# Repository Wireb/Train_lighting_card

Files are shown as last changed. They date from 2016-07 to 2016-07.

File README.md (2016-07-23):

### Induction refractory furnance supporting files

### licence 
Copyright (c) 2015 Peter Shabino

Permission is hereby granted, free of charge, to any person obtaining a copy of this hardware, software, and associated documentation files
(the "Product"), to deal in the Product without restriction, including without limitation the rights to use, copy, modify, merge, publish,
distribute, sublicense, and/or sell copies of the Product, and to permit persons to whom the Product is furnished to do so, subject to the
following conditions:

The above copyright notice and this permission notice shall be included in all copies or substantial portions of the Product.

THE PRODUCT IS PROVIDED "AS IS", WITHOUT WARRANTY OF ANY KIND, EXPRESS OR IMPLIED, INCLUDING BUT NOT LIMITED TO THE WARRANTIES OF
MERCHANTABILITY, FITNESS FOR A PARTICULAR PURPOSE AND NONINFRINGEMENT. IN NO EVENT SHALL THE AUTHORS OR COPYRIGHT HOLDERS BE LIABLE
FOR ANY CLAIM, DAMAGES OR OTHER LIABILITY, WHETHER IN AN ACTION OF CONTRACT, TORT OR OTHERWISE, ARISING FROM, OUT OF OR IN CONNECTION
WITH THE PRODUCT OR THE USE OR OTHER DEALINGS IN THE PRODUCT.

### What is it
The current generation of controller card supports up to 11 normal LED channels plus one "special"  one that supports driving a bi-polar output. On the input side the controller will run off 6V to 60V AC or DC. (note I have NOT test this full range. I have tested 9Vac to 20Vac with no issues) It also has 4 opto-isolated inputs that will respond to ~3V to 32V AC or DC that can be used to pick one of 16 pre-programmed states. 

Currently there are 7 selectable states:
* Headlights
* running lights
* left turn
* right turn
* break lights
* reverse lights
* light bar flashers 

Via the programing button any state, combination of states, or none can be chosen for each of the 16 combinations of the 4 inputs.

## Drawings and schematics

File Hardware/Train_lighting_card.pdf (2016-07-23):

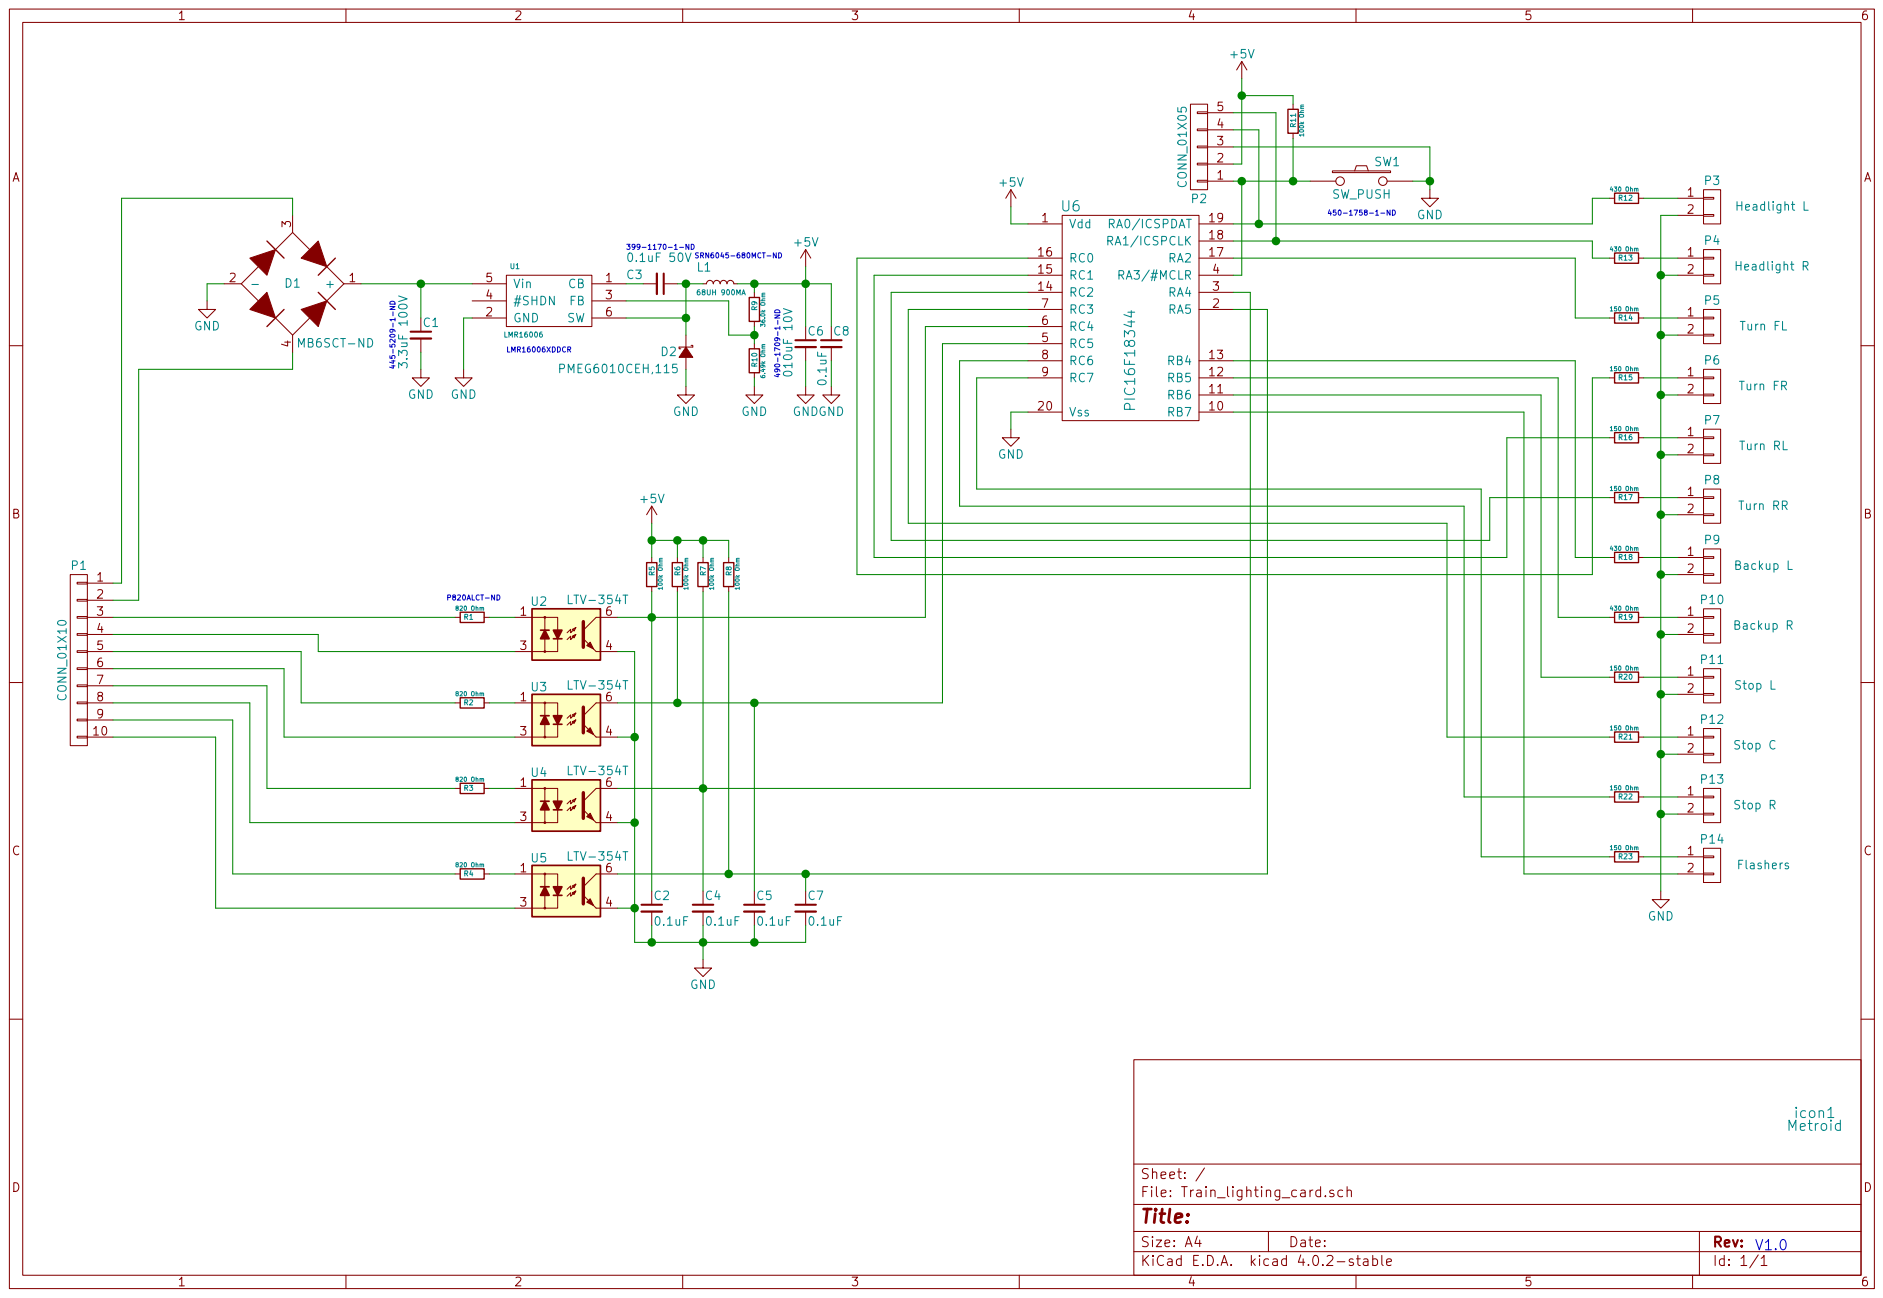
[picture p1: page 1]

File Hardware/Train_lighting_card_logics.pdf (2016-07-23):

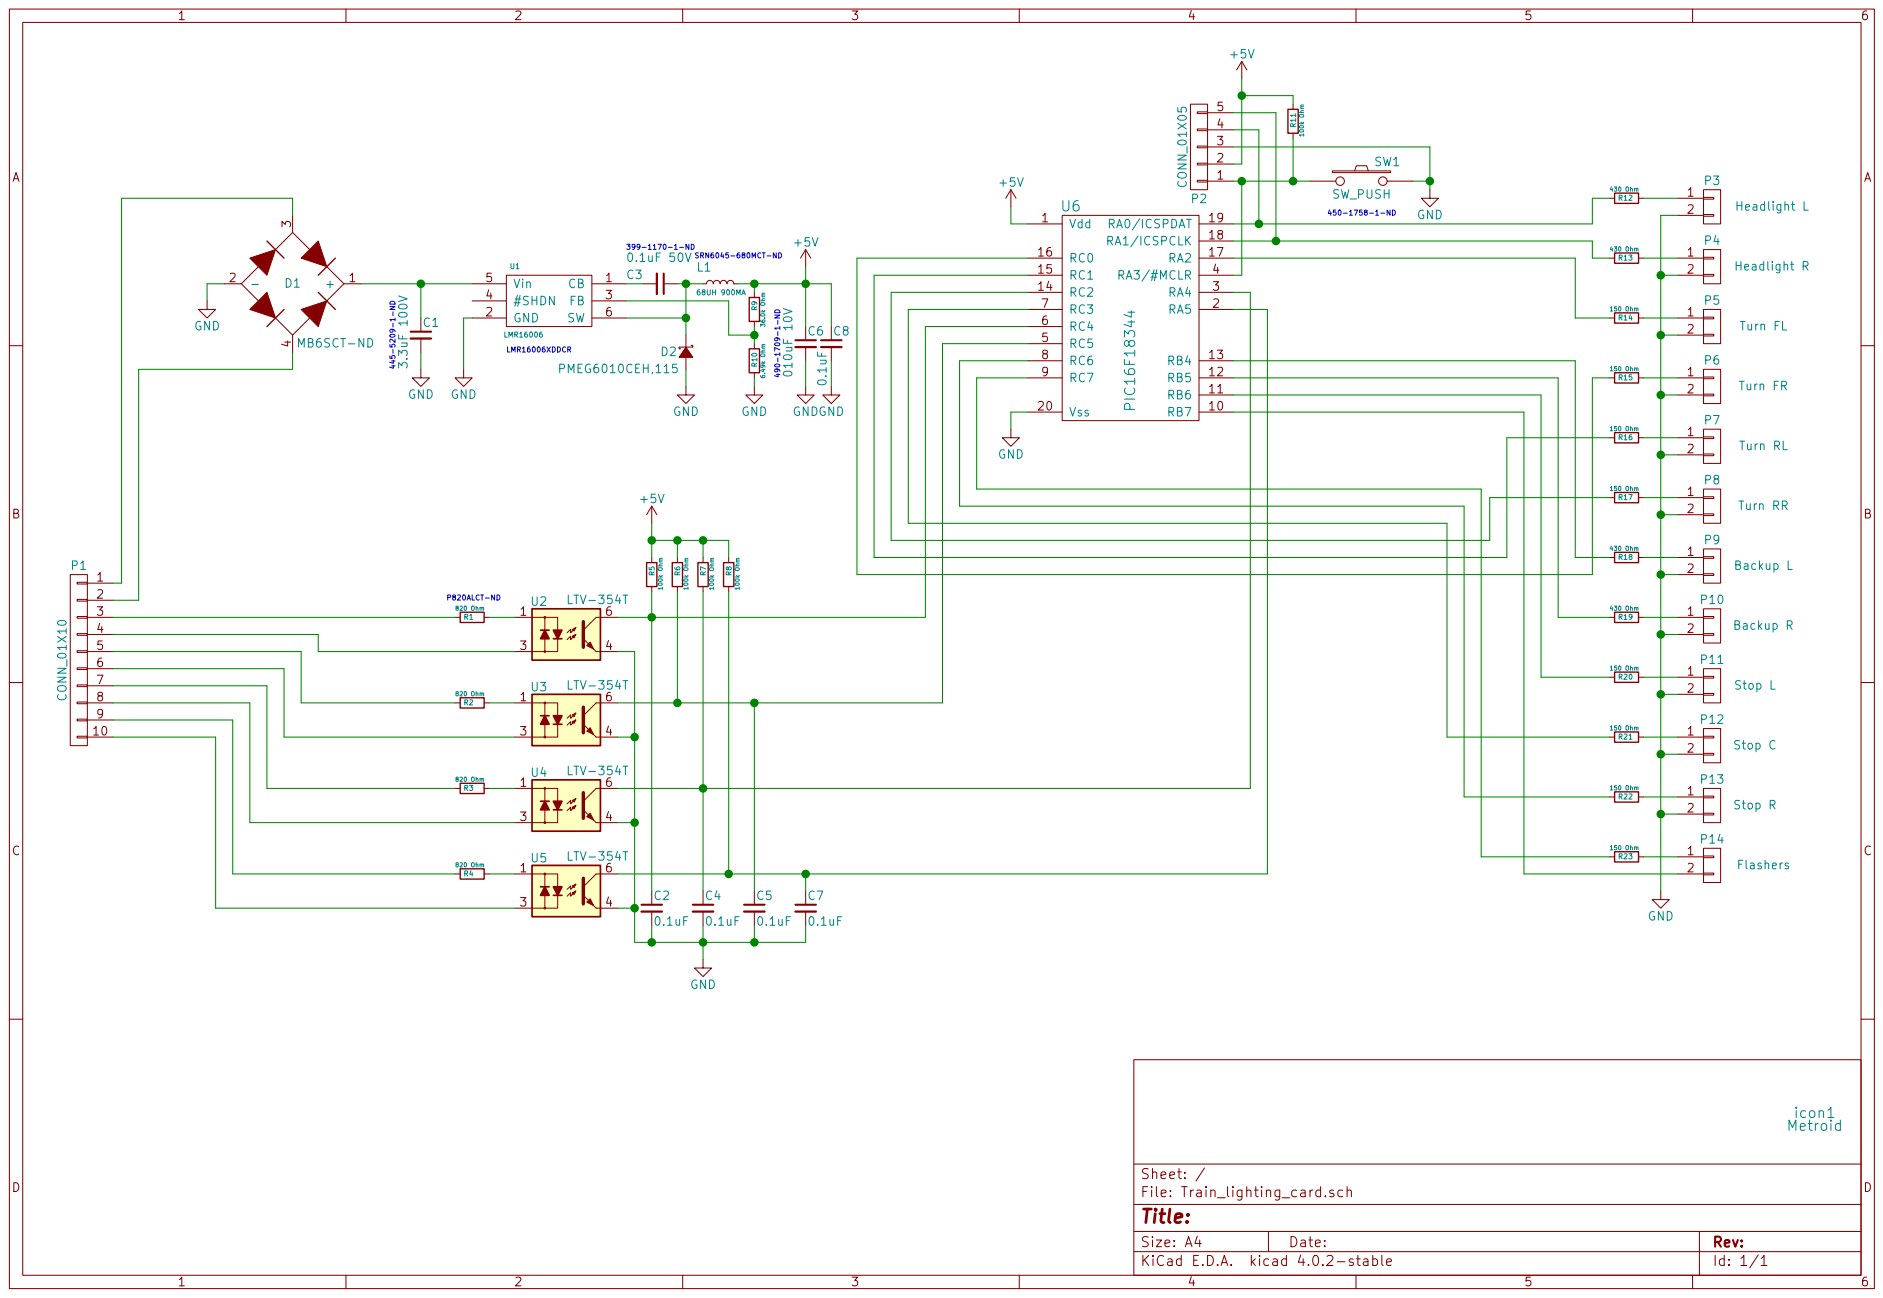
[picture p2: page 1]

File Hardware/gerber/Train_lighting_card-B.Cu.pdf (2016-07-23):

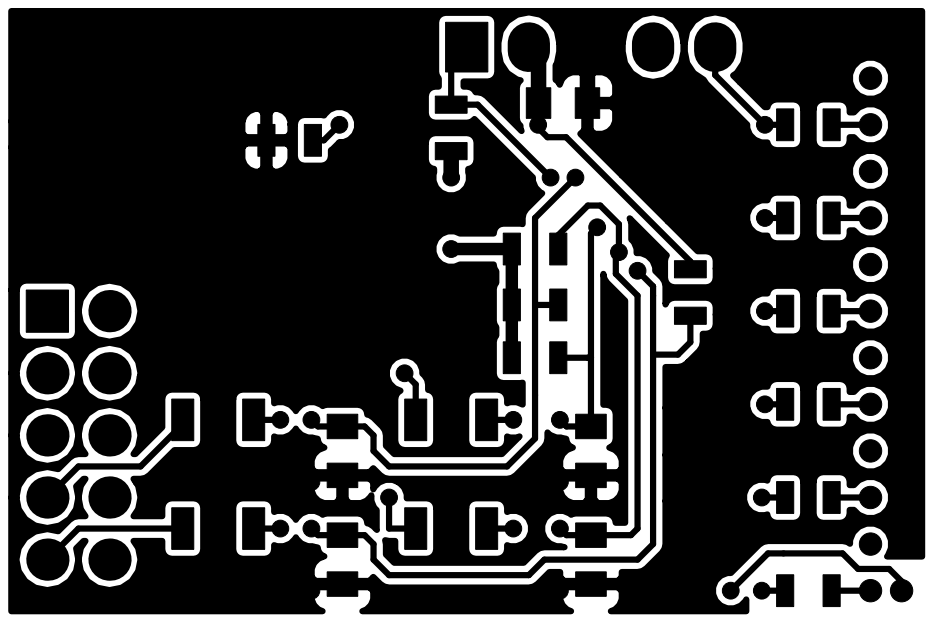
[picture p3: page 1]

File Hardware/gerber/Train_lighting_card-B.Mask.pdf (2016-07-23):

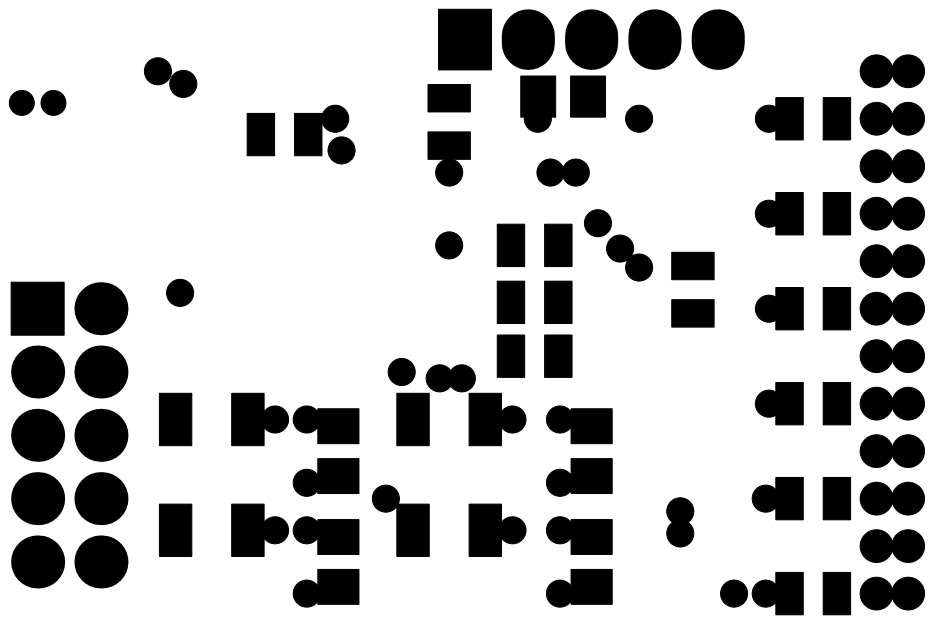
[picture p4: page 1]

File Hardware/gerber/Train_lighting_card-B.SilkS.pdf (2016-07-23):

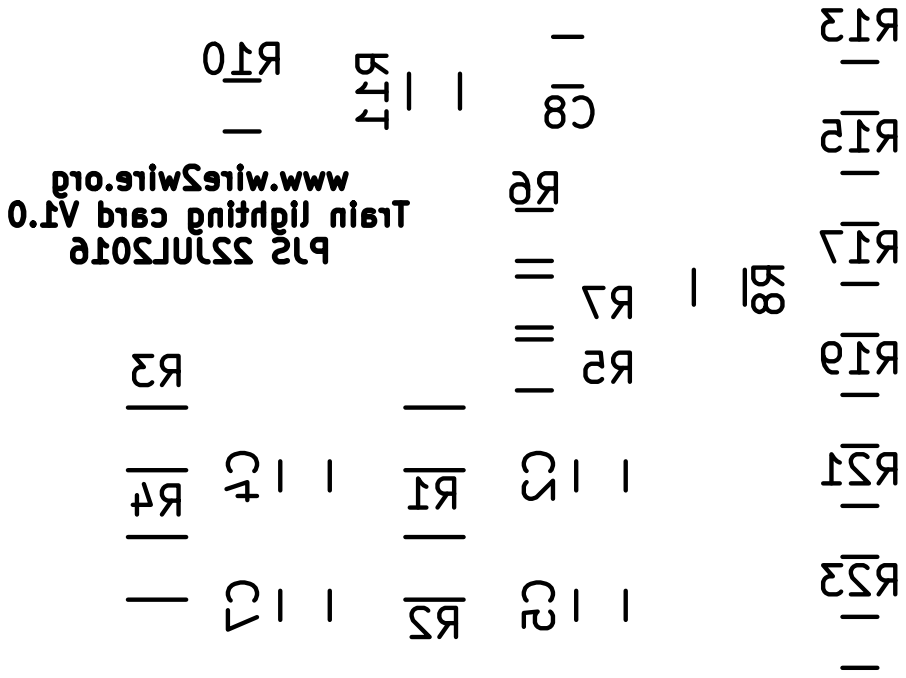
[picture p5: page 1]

Train lighting card V1.0 PJS 22JUL2016 C4 C2 C7 C5 R1 R2 R3 R4 R5 R6 R7 R8 R10 R11 R13 R15 R17 R19 R21 R23 C8

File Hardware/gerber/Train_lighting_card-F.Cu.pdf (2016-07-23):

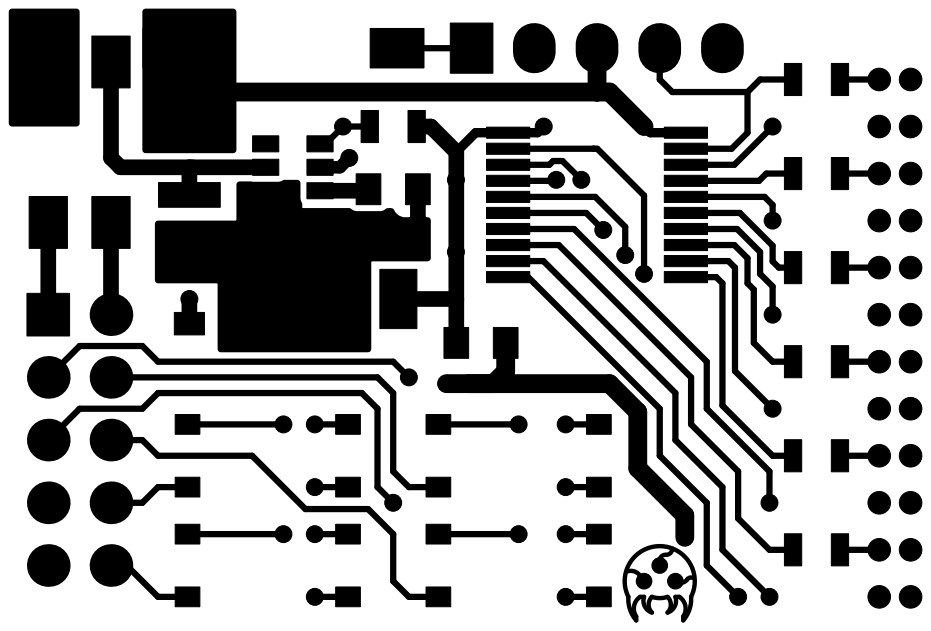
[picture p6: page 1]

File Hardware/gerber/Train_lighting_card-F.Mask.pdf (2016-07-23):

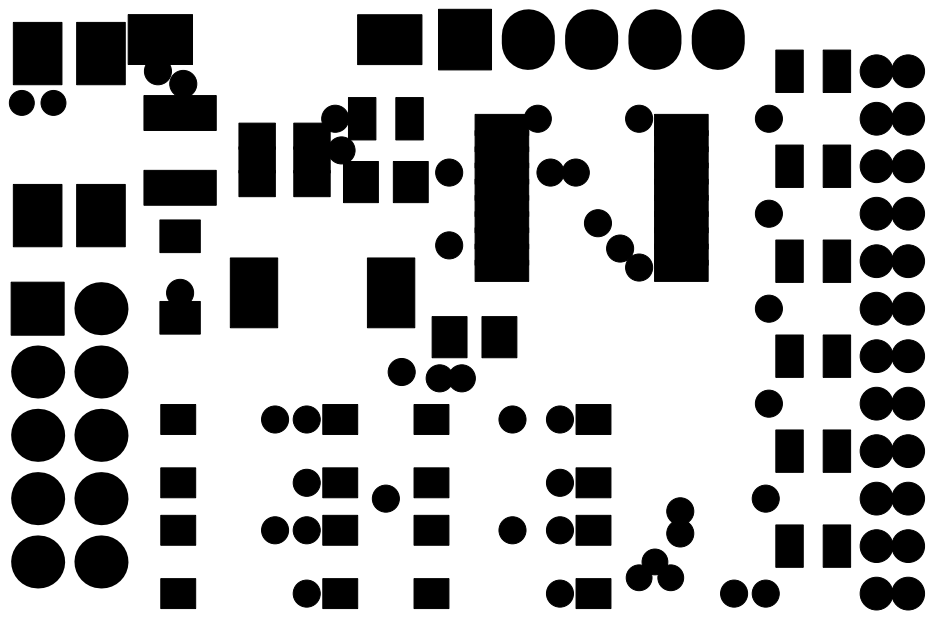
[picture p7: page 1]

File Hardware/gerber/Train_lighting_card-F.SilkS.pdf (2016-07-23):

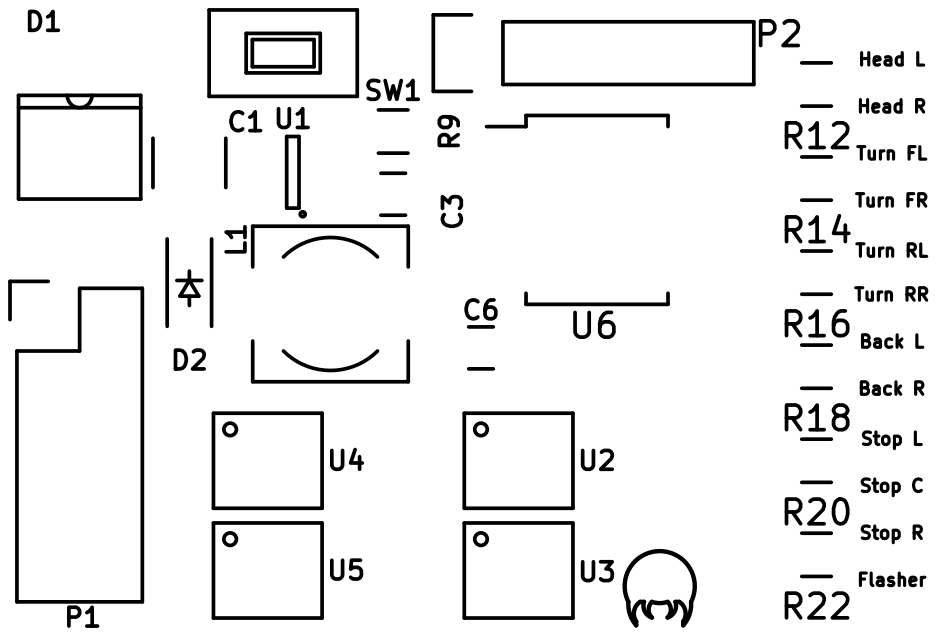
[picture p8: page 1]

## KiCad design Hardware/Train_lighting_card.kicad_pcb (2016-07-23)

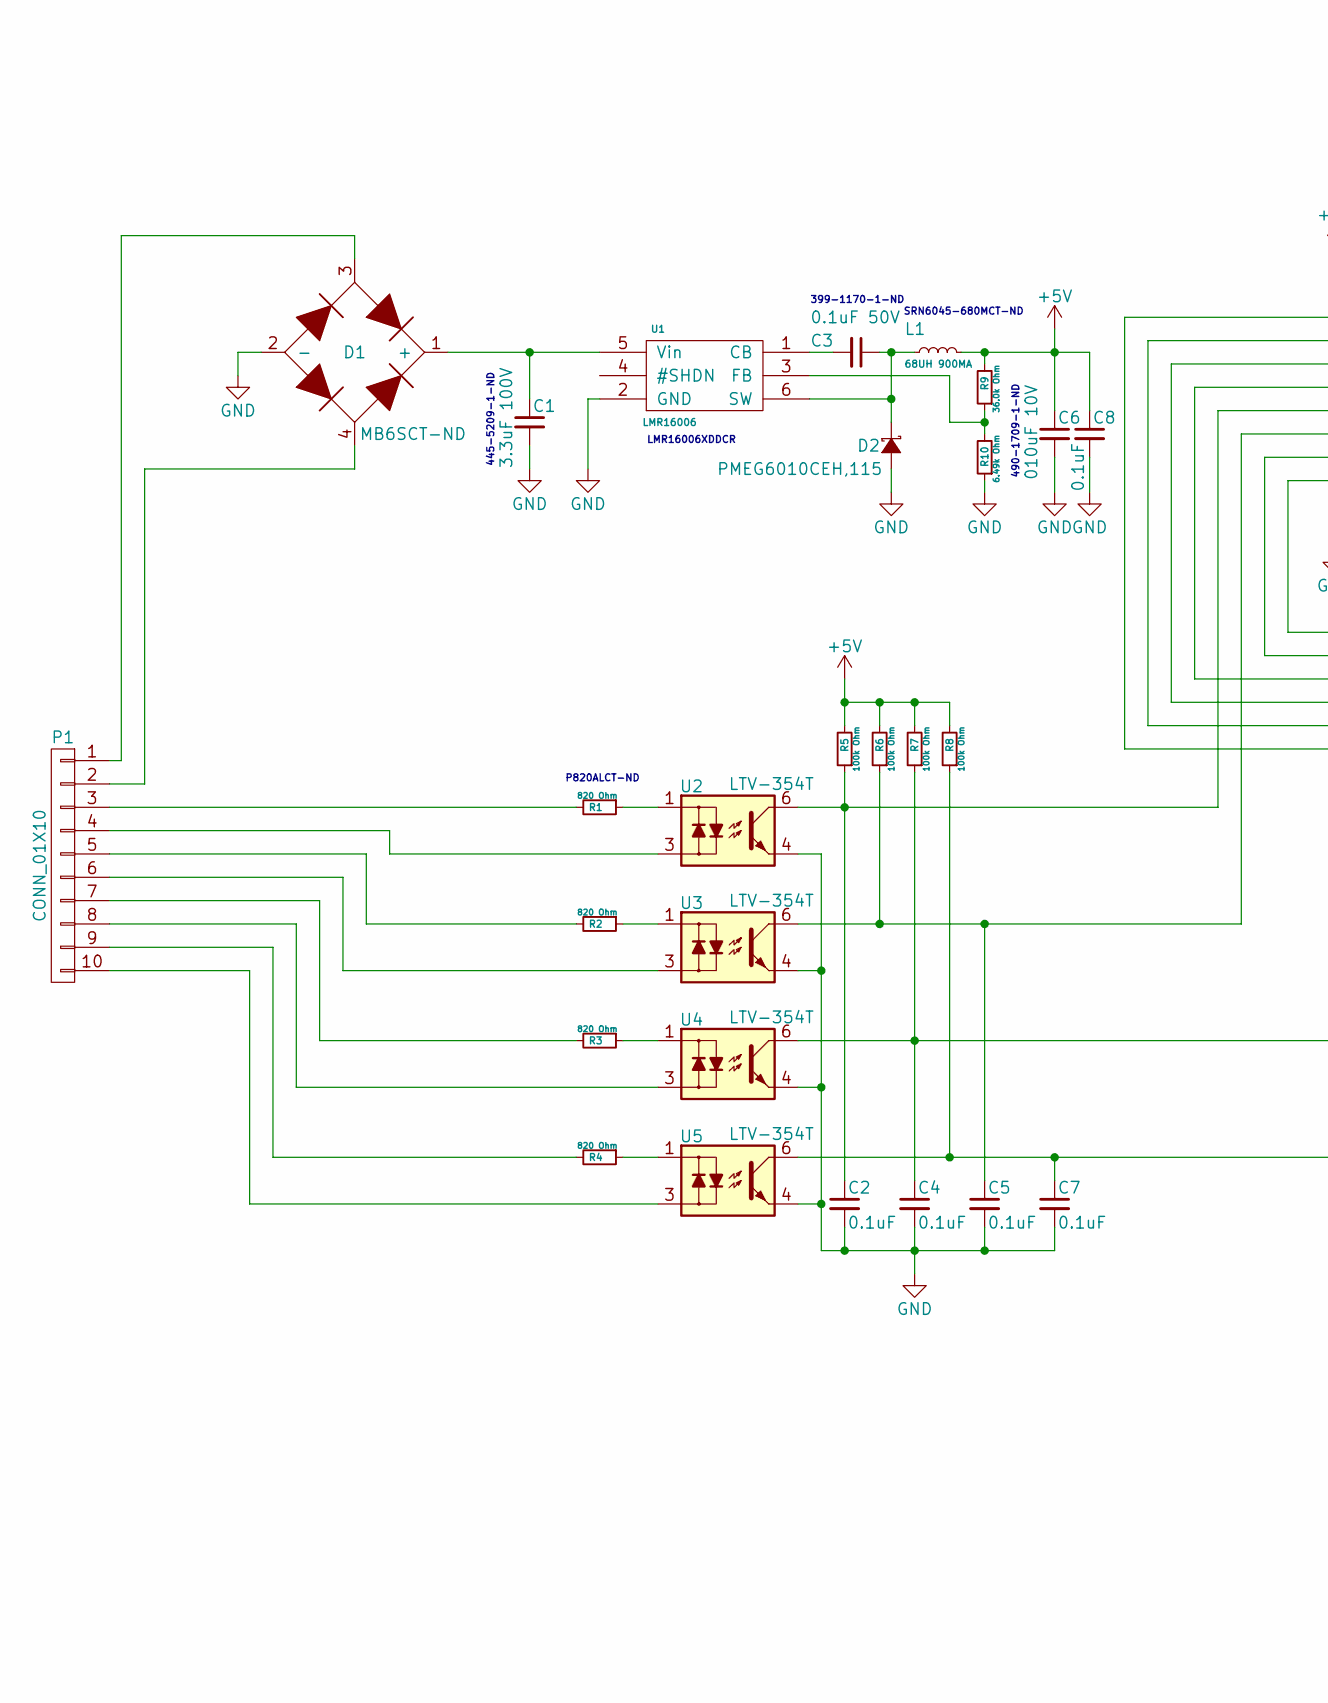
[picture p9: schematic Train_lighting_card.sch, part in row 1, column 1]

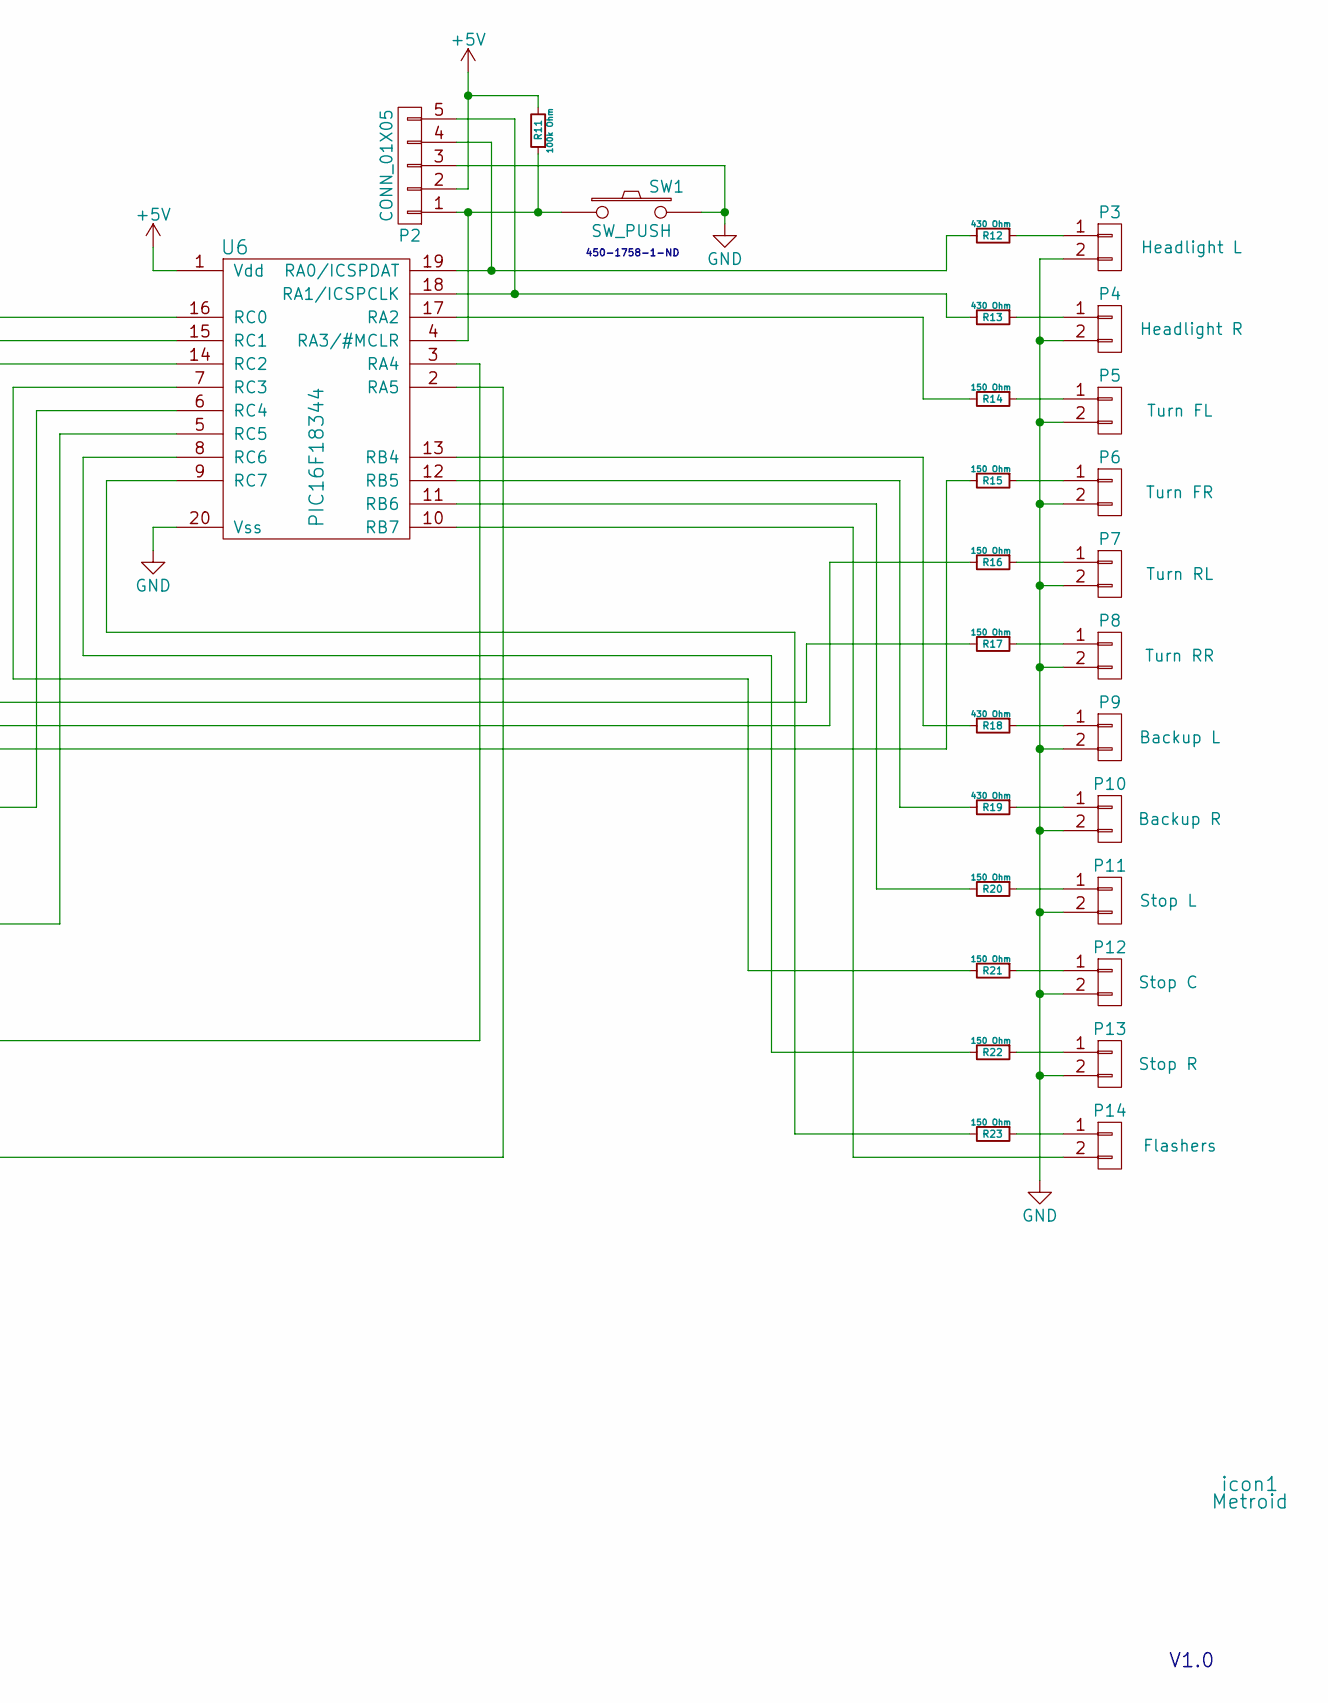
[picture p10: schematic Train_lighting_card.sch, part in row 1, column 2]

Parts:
C1: 3.3uF 100V; C_1210
C2, C4, C5, C7, C8: 0.1uF; C_0805
C3: 0.1uF 50V; C_0805
C6: 010uF 10V; C_0805
D1: MB6SCT-ND
D2: PMEG6010CEH,115; SOD-123
L1: 68UH 900MA; Choke_SMD_6.3x6.3_H3
P1: CONN_01X10; Pin_Header_Straight_2x05
P2: CONN_01X05; Pin_Header_Straight_1x05
P3: Headlight L; wirepad_x2_20mil
P4: Headlight R; wirepad_x2_20mil
P5: Turn FL; wirepad_x2_20mil
P6: Turn FR; wirepad_x2_20mil
P7: Turn RL; wirepad_x2_20mil
P8: Turn RR; wirepad_x2_20mil
P9: Backup L; wirepad_x2_20mil
P10: Backup R; wirepad_x2_20mil
P11: Stop L; wirepad_x2_20mil
P12: Stop C; wirepad_x2_20mil
P13: Stop R; wirepad_x2_20mil
P14: Flashers; wirepad_x2_20mil
R1, R2, R3, R4: 820 Ohm; R_1206
R5, R6, R7, R8, R11: 100k Ohm; R_0805
R9: 36.0k Ohm; R_0805
R10: 6.49k Ohm; R_0805
R12, R13, R18, R19: 430 Ohm; R_0805
R14, R15, R16, R17, R20, R21, R22, R23: 150 Ohm; R_0805
SW1: SW_PUSH; SW_SPST_FSMSM
U1: LMR16006; SOT-23-6
U2, U3, U4, U5: LTV-354T; SOP-6-4
U6: PIC16F18344; SSOP-20_5.3x7.2mm_Pitch0.65mm
icon1: Metroid; metroid

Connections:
+5V: C6.1, C8.1, L1.2, P2.2, R5.2, R6.2, R7.2, R8.2, R9.2, R11.2, U6.1 (Vdd)
GND: C1.2, C2.2, C4.2, C5.2, C6.2, C7.2, C8.2, D1.2 (-), D2.2 (A), P2.3, P3.2, P4.2, P5.2, P6.2, P7.2, P8.2, P9.2, P10.2, P11.2, P12.2, P13.2, R10.1, SW1.2, U1.2 (GND), U2.4, U3.4, U4.4, U5.4, U6.20 (Vss)
unnamed: C1.1, D1.1 (+), U1.5 (Vin)
unnamed: C2.1, R5.1, U2.6, U6.6 (RC4)
unnamed: C3.1, D2.1 (K), L1.1, U1.6 (SW)
unnamed: C3.2, U1.1 (CB)
unnamed: C4.1, R7.1, U4.6, U6.3 (RA4)
unnamed: C5.1, R6.1, U3.6, U6.5 (RC5)
unnamed: C7.1, R8.1, U5.6, U6.2 (RA5)
unnamed: D1.3, P1.1
unnamed: D1.4, P1.2
unnamed: P1.3, R1.2
unnamed: P1.4, U2.3
unnamed: P1.5, R2.2
unnamed: P1.6, U3.3
unnamed: P1.7, R3.2
unnamed: P1.8, U4.3
unnamed: P1.9, R4.2
unnamed: P1.10, U5.3
unnamed: P2.1, R11.1, SW1.1, U6.4 (RA3/#MCLR)
unnamed: P2.4, R12.2, U6.19 (RA0/ICSPDAT)
unnamed: P2.5, R13.2, U6.18 (RA1/ICSPCLK)
unnamed: P3.1, R12.1
unnamed: P4.1, R13.1
unnamed: P5.1, R14.1
unnamed: P6.1, R15.1
unnamed: P7.1, R16.1
unnamed: P8.1, R17.1
unnamed: P9.1, R18.1
unnamed: P10.1, R19.1
unnamed: P11.1, R20.1
unnamed: P12.1, R21.1
unnamed: P13.1, R22.1
unnamed: P14.1, R23.1
unnamed: P14.2, U6.10 (RB7)
unnamed: R1.1, U2.1
unnamed: R2.1, U3.1
unnamed: R3.1, U4.1
unnamed: R4.1, U5.1
unnamed: R9.1, R10.2, U1.3 (FB)
unnamed: R14.2, U6.17 (RA2)
unnamed: R15.2, U6.16 (RC0)
unnamed: R16.2, U6.15 (RC1)
unnamed: R17.2, U6.14 (RC2)
unnamed: R18.2, U6.13 (RB4)
unnamed: R19.2, U6.12 (RB5)
unnamed: R20.2, U6.11 (RB6)
unnamed: R21.2, U6.7 (RC3)
unnamed: R22.2, U6.8 (RC6)
unnamed: R23.2, U6.9 (RC7)

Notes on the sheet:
P820ALCT-ND
445-5209-1-ND
LMR16006XDDCR
399-1170-1-ND
SRN6045-680MCT-ND
490-1709-1-ND
450-1758-1-ND
V1.0

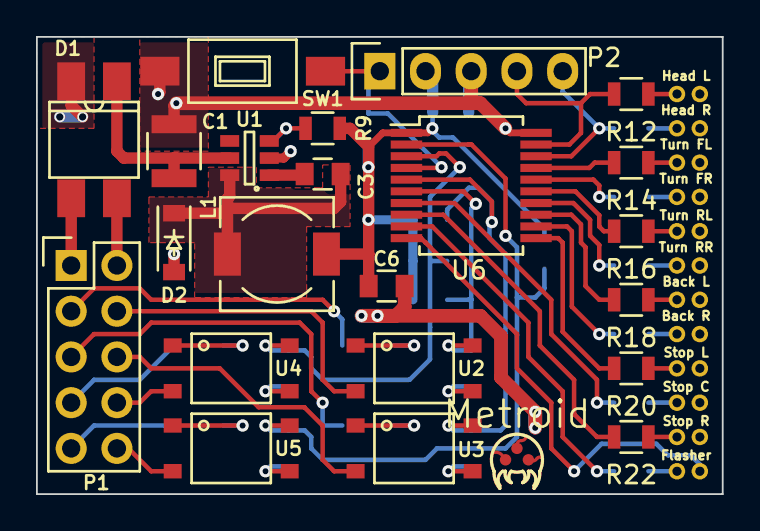
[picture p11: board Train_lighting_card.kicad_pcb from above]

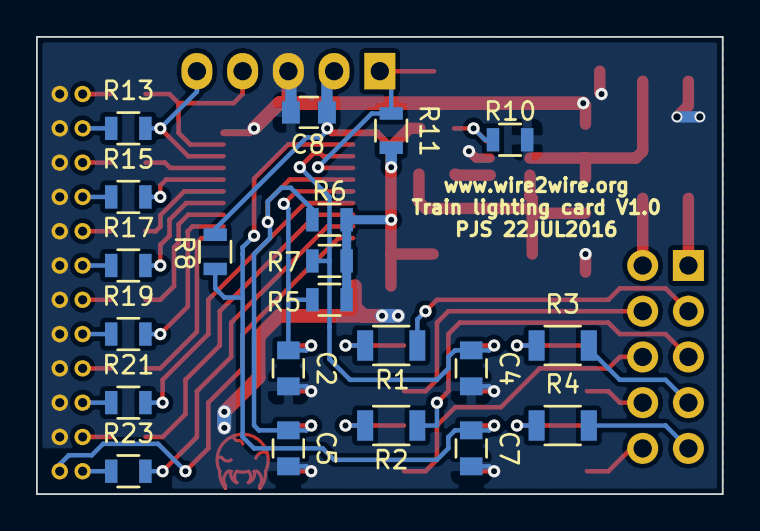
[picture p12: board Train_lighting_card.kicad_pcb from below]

Board: 2 copper layers, 38.1 x 25.4 mm, 56 parts (21 on the bottom side), 50 nets.

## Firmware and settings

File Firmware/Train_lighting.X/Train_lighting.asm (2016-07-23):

;#############################################################################################################################################
;#Copyright (c) 2015 Peter Shabino
;#
;#Permission is hereby granted, free of charge, to any person obtaining a copy of this hardware, software, and associated documentation files
;#(the "Product"), to deal in the Product without restriction, including without limitation the rights to use, copy, modify, merge, publish,
;#distribute, sublicense, and/or sell copies of the Product, and to permit persons to whom the Product is furnished to do so, subject to the
;#following conditions:
;#
;#The above copyright notice and this permission notice shall be included in all copies or substantial portions of the Product.
;#
;#THE PRODUCT IS PROVIDED "AS IS", WITHOUT WARRANTY OF ANY KIND, EXPRESS OR IMPLIED, INCLUDING BUT NOT LIMITED TO THE WARRANTIES OF
;#MERCHANTABILITY, FITNESS FOR A PARTICULAR PURPOSE AND NONINFRINGEMENT. IN NO EVENT SHALL THE AUTHORS OR COPYRIGHT HOLDERS BE LIABLE
;#FOR ANY CLAIM, DAMAGES OR OTHER LIABILITY, WHETHER IN AN ACTION OF CONTRACT, TORT OR OTHERWISE, ARISING FROM, OUT OF OR IN CONNECTION
;#WITH THE PRODUCT OR THE USE OR OTHER DEALINGS IN THE PRODUCT.
;#############################################################################################################################################

; This is the Train lighting micro code
; 04DEC15 V00.00 PJS New
; 10JUN16 V00.01 PJS Added support for flashers, turn signal blinking, state inputs and started eeprom support
; 15JUL16 V00.02 PJS Started EEPROM support. 

VerHigh	    equ	    0x00
VerLow	    equ	    0x02
#define	CODE_VER_STRING "Peter Shabino 15JUL2016 Train Lighting V00.02" ;Just in ROM

;****************************************************************************************
; port list
; Vss(20)[3]		GND
; Vdd(1)[2]		+V
; RA0(19)[4]		ICSPDAT, Headlight L
; RA1(18)[5]		ICSPCLK, Headlight R
; RA2(17)		Turn FL
; RA3(4)[1]		Vpp/#MCLR, button
; RA4(3)		input
; RA5(2)		input
; RB4(13)		backup L
; RB5(12)		backup R
; RB6(11)		stop L
; RB7(10)		flasher A
; RC0(16)		turn FR
; RC1(15)		turn RL
; RC2(14)		turn RR
; RC3(7)		stop C
; RC4(6)		input
; RC5(5)		input
; RC6(8)		stop R
; RC7(9)		flasher B
;****************************************************************************************

;-----------------------------------------------------------------------------------------------------------
; compiler configuration
;-----------------------------------------------------------------------------------------------------------
	; set processor type and output file type (intel merged hex (.hex))
	list	f=INHX8M
	
	; PIC16F18344 Configuration Bit Settings
	#include "p16F18344.inc"
	; CONFIG1
	; __config 0xFFEC
	 __CONFIG _CONFIG1, _FEXTOSC_OFF & _RSTOSC_HFINT1 & _CLKOUTEN_OFF & _CSWEN_ON & _FCMEN_ON
	; CONFIG2
	; __config 0xF7D0
	 __CONFIG _CONFIG2, _MCLRE_OFF & _PWRTE_ON & _WDTE_OFF & _LPBOREN_ON & _BOREN_ON & _BORV_LOW & _PPS1WAY_OFF & _STVREN_ON & _DEBUG_OFF
	; CONFIG3
	; __config 0x3
	 __CONFIG _CONFIG3, _WRT_OFF & _LVP_OFF
	; CONFIG4
	; __config 0x3
	 __CONFIG _CONFIG4, _CP_OFF & _CPD_OFF

;-----------------------------------------------------------------------------------------------------------
;constants
;-----------------------------------------------------------------------------------------------------------

;-----------------------------------------------------------------------------------------------------------
;variables (0x20 - 0x6F only), 0x0A0-0x0BF
;-----------------------------------------------------------------------------------------------------------
; bank 0  
temp		equ	    0x20
last_state	equ	    0x21
blink_count	equ	    0x22
eeprom_update	equ	    0x23
button_bounce	equ	    0x24
init		equ	    0x25

state_regs_H	equ	    0x00
state_regs_L	equ	    0x30
;		equ	    0x31
;		equ	    0x32
;		equ	    0x33
;		equ	    0x34
;		equ	    0x35
;		equ	    0x36
;		equ	    0x37
;		equ	    0x38
;		equ	    0x39
;		equ	    0x3A
;		equ	    0x3B
;		equ	    0x3C
;		equ	    0x3D
;		equ	    0x3E
;		equ	    0x3F


	
;-----------------------------------------------------------------------------------------------------------
;global variables (0x70 - 0x7F only)
;-----------------------------------------------------------------------------------------------------------
global_temp	equ	    0x70
	
;-----------------------------------------------------------------------------------------------------------
;EEPROM data
;   bit 0 = headlights
;   bit 1 = running lights
;   bit 2 = left turn
;   bit 3 = right turn
;   bit 4 = backup
;   bit 5 = stop lights
;   bit 6 = flashers
; byte order input signals inverted. So all open would be the last value (right).
;-----------------------------------------------------------------------------------------------------------
	org     0xF000
	de	0x00,0x00,0x00,0x00,0x00,0x00,0x00,0x00,0x00,0x40,0x20,0x10,0x08,0x04,0x03,0xFF

	
	
;-----------------------------------------------------------------------------------------------------------
;put the following at address 0000h (starting vector)
;-----------------------------------------------------------------------------------------------------------
	org     0000h
	goto	START		    ; normal boot / reset vector

;-----------------------------------------------------------------------------------------------------------
;put the following at address 0004h (IRQ vector)
;-----------------------------------------------------------------------------------------------------------
	org     0004h
	goto	IRQ		    ; catch all IRQ not used
	
	
	
;-----------------------------------------------------------------------------------------------------------
;interrup routine
;-----------------------------------------------------------------------------------------------------------
IRQ	
        ; pic automaticly stores all critical data and disables the GIE
        movlb   d'00'		    ; make sure we are in bank 0
	
	; todo if needed add check for multiple irqs here. 
	
	bcf	PIR0, TMR0IF	    ; clear the irq 
	
	incf	blink_count, F	    ; inc the blinker state
	
	; button debounce code
	bcf	STATUS, C
	rrf	button_bounce, F
	
	; eeprom update trigger
	movf	eeprom_update, W
	btfsc	STATUS, Z
	goto	EEPROM_NO_UPDATE
	xorlw	0x01
	btfsc	STATUS, Z
	goto	EEPROM_UPDATE
	decf	eeprom_update, F
	goto	EEPROM_NO_UPDATE
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
